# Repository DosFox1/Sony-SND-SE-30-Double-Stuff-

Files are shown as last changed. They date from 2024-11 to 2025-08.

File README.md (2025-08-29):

# Sony-SND-SE-30-Double-Stuff
BETA - A replacement for the Sony SND IC (part number 343-0045-A), specifically designed for the SE/30.
This design is a duplication of the previous Sony SND SMD version, but literally copied twice to fit two Sony SNDs onto the board without the DRC yelling at me.




# So What Is It?
This is quite literally the same design as before, with the same improvement of not needing the -12V rail. 
However, due to the board constraints of the SE/30, two of my SMD boards will not fit - at least easily. 
So this design just adds a second SND replacement so the DRC doesn't yell at me. 

It's all common jellybean parts, so nothing hyper specific is needed.

**Please note that -12V will need to be tapped from somewhere on the board, otherwise the audio doesn't work.**

**Also the 27R Pullup resistor at R11 on the logic board needs to be removed, otherwise POR doesn't work!**

The original SMD Design is here:
https://github.com/DosFox1/Sony-SND-SMT-Replacement

And the very original THT design is here:
https://github.com/DosFox1/Sony-SND-THT-Replacement

**Please Also Note That This Is Completely Untested, Build At Your Own Risk**

# Bill Of Materials:

```blocks
Part     Value          Device                       Package  Library                Sheet

C1       100n 16V       100N_CAP_0603                C0603    Capacitors SMD         1
C2       100n 16V       100N_CAP_0603                C0603    Capacitors SMD         1
C3       100n 16V       100N_CAP_0603                C0603    Capacitors SMD         1
C4       100n 16V       100N_CAP_0603                C0603    Capacitors SMD         1
C5       1u 16V         1U_CAP_0603                  C0603    Capacitors SMD         1
C6       100n 16V       100N_CAP_0603                C0603    Capacitors SMD         1
C7       470p           100P_CAP_0603                C0603    Capacitors SMD         1
C8       1n 50V         10N_CAP_0603                 C0603    Capacitors SMD         1
C9       100n 16V       100N_CAP_0603                C0603    Capacitors SMD         1
C10      100n 16V       100N_CAP_0603                C0603    Capacitors SMD         1
C11      220p           100P_CAP_0603                C0603    Capacitors SMD         1
C12      100n 16V       100N_CAP_0603                C0603    Capacitors SMD         1
C13      100n 16V       100N_CAP_0603                C0603    Capacitors SMD         1
C14      100n 16V       100N_CAP_0603                C0603    Capacitors SMD         1
C15      100n 16V       100N_CAP_0603                C0603    Capacitors SMD         1
C16      100n 16V       100N_CAP_0603                C0603    Capacitors SMD         1
C17      470p           100P_CAP_0603                C0603    Capacitors SMD         1
C18      1n 50V         10N_CAP_0603                 C0603    Capacitors SMD         1
C19      100n 16V       100N_CAP_0603                C0603    Capacitors SMD         1
C20      100n 16V       100N_CAP_0603                C0603    Capacitors SMD         1
C21      220p           100P_CAP_0603                C0603    Capacitors SMD         1
C22      100n 16V       100N_CAP_0603                C0603    Capacitors SMD         1
C23      1u 16V         1U_CAP_0603                  C0603    Capacitors SMD         1
C24      100n 16V       100N_CAP_0603                C0603    Capacitors SMD         1
D1       5.1V           DIODE-ZENER-MMSZ5232BS       SOD-123  SparkFun-DiscreteSemi  1
D2       5.1V           DIODE-ZENER-MMSZ5232BS       SOD-123  SparkFun-DiscreteSemi  1
IC1      TL072          OPAMP-DUALU                  SO08     SparkFun-IC-Amplifiers 1
IC2      4016D          4016D                        SO14     40xx                   1
IC3      NE555DRG4      555_SOIC8                    SOIC8    ICs                    1
IC4      74LVC1G06DBV   74LVC1G06DBV                 SOT23-5  74xx-little-us         1
IC5      Turned Pins    SND Turned Pins              DIP16    Pins                   1
IC6      4016D          4016D                        SO14     40xx                   1
IC7      Turned Pins    SND Turned Pins              DIP16    ICs                    1
IC8      74LVC1G06DBV   74LVC1G06DBV                 SOT23-5  74xx-little-us         1
IC9      NE555DRG4      555_SOIC8                    SOIC8    Pins                   1
IC10     TL072          OPAMP-DUALU                  SO08     SparkFun-IC-Amplifiers 1
Q1       MMBT3906       TRANS_PNP-PMBT3906|MMBT3906L SOT23-3  SparkFun-DiscreteSemi  1
Q2       MMBT3904       TRANS_NPN-MMBT2222AL         SOT23-3  SparkFun-DiscreteSemi  1
Q3       MMBT3906       TRANS_PNP-PMBT3906|MMBT3906L SOT23-3  SparkFun-DiscreteSemi  1
Q4       MMBT3904       TRANS_NPN-MMBT2222AL         SOT23-3  SparkFun-DiscreteSemi  1
R1       1M             GENERIC_RESISTOR_0603        R0603    Resistors SMD          1
R2       1M             GENERIC_RESISTOR_0603        R0603    Resistors SMD          1
R3       6K8            GENERIC_RESISTOR_0603        R0603    Resistors SMD          1
R4       47K            47K_RESISTOR                 R0603    Resistors SMD          1
R5       1k             1K_RESISTOR_0603             R0603    Resistors SMD          1
R6       47K            47K_RESISTOR                 R0603    Resistors SMD          1
R7       68K            GENERIC_RESISTOR_0603        R0603    Resistors SMD          1
R8       150K           GENERIC_RESISTOR_0603        R0603    Resistors SMD          1
R9       470K           GENERIC_RESISTOR_0603        R0603    Resistors SMD          1
R10      470K           GENERIC_RESISTOR_0603        R0603    Resistors SMD          1
R11      200K           GENERIC_RESISTOR_0603        R0603    Resistors SMD          1
R12      150R           150R_RESISTOR_0603           R0603    Resistors SMD          1
R13      47K            47K_RESISTOR                 R0603    Resistors SMD          1
R14      47K            47K_RESISTOR                 R0603    Resistors SMD          1
R15      1M             GENERIC_RESISTOR_0603        R0603    Resistors SMD          1
R16      1M             GENERIC_RESISTOR_0603        R0603    Resistors SMD          1
R17      1k             1K_RESISTOR_0603             R0603    Resistors SMD          1
R18      6K8            GENERIC_RESISTOR_0603        R0603    Resistors SMD          1
R19      68K            GENERIC_RESISTOR_0603        R0603    Resistors SMD          1
R20      150K           GENERIC_RESISTOR_0603        R0603    Resistors SMD          1
R21      470K           GENERIC_RESISTOR_0603        R0603    Resistors SMD          1
R22      470K           GENERIC_RESISTOR_0603        R0603    Resistors SMD          1
R23      200K           GENERIC_RESISTOR_0603        R0603    Resistors SMD          1
R24      150R           150R_RESISTOR_0603           R0603    Resistors SMD          1

```

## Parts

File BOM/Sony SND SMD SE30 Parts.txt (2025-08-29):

Partlist

Exported from SND_SMD_Replacement.sch at 31/Oct/24 13:54

EAGLE Version 9.6.2 Copyright (c) 1988-2020 Autodesk, Inc.

Assembly variant: 

Part     Value          Device                       Package  Library                Sheet

C1       100n 16V       100N_CAP_0603                C0603    Capacitors SMD         1
C2       100n 16V       100N_CAP_0603                C0603    Capacitors SMD         1
C3       100n 16V       100N_CAP_0603                C0603    Capacitors SMD         1
C4       100n 16V       100N_CAP_0603                C0603    Capacitors SMD         1
C5       1u 16V         1U_CAP_0603                  C0603    Capacitors SMD         1
C6       100n 16V       100N_CAP_0603                C0603    Capacitors SMD         1
C7       470p           470P_CAP_0603                C0603    Capacitors SMD         1
C8       1n 50V         1N_CAP_0603                  C0603    Capacitors SMD         1
C9       100n 16V       100N_CAP_0603                C0603    Capacitors SMD         1
C10      100n 16V       100N_CAP_0603                C0603    Capacitors SMD         1
C11      220p           220P_CAP_0603                C0603    Capacitors SMD         1
C12      100n 16V       100N_CAP_0603                C0603    Capacitors SMD         1
C13      100n 16V       100N_CAP_0603                C0603    Capacitors SMD         1
C14      100n 16V       100N_CAP_0603                C0603    Capacitors SMD         1
C15      100n 16V       100N_CAP_0603                C0603    Capacitors SMD         1
C16      100n 16V       100N_CAP_0603                C0603    Capacitors SMD         1
C17      470p           470P_CAP_0603                C0603    Capacitors SMD         1
C18      1n 50V         1N_CAP_0603                  C0603    Capacitors SMD         1
C19      100n 16V       100N_CAP_0603                C0603    Capacitors SMD         1
C20      100n 16V       100N_CAP_0603                C0603    Capacitors SMD         1
C21      220p           220P_CAP_0603                C0603    Capacitors SMD         1
C22      100n 16V       100N_CAP_0603                C0603    Capacitors SMD         1
C23      1u 16V         1U_CAP_0603                  C0603    Capacitors SMD         1
C24      100n 16V       100N_CAP_0603                C0603    Capacitors SMD         1
D1       5.1V           DIODE-ZENER-MMSZ5232BS       SOD-123  SparkFun-DiscreteSemi  1
D2       5.1V           DIODE-ZENER-MMSZ5232BS       SOD-123  SparkFun-DiscreteSemi  1
IC1      TL072          OPAMP-DUALU                  SO08     SparkFun-IC-Amplifiers 1
IC2      4016D          4016D                        SO14     40xx                   1
IC3      NE555DRG4      555_SOIC8                    SOIC8    ICs                    1
IC4      74LVC1G06DBV   74LVC1G06DBV                 SOT23-5  74xx-little-us         1
IC5                     SND                          DIP16    ICs                    1
IC6      4016D          4016D                        SO14     40xx                   1
IC7                     SND                          DIP16    ICs                    1
IC8      74LVC1G06DBV   74LVC1G06DBV                 SOT23-5  74xx-little-us         1
IC9      NE555DRG4      555_SOIC8                    SOIC8    ICs                    1
IC10     TL072          OPAMP-DUALU                  SO08     SparkFun-IC-Amplifiers 1
Q1       MMBT3906       TRANS_PNP-PMBT3906|MMBT3906L SOT23-3  SparkFun-DiscreteSemi  1
Q2       MMBT3904       TRANS_NPN-MMBT2222AL         SOT23-3  SparkFun-DiscreteSemi  1
Q3       MMBT3906       TRANS_PNP-PMBT3906|MMBT3906L SOT23-3  SparkFun-DiscreteSemi  1
Q4       MMBT3904       TRANS_NPN-MMBT2222AL         SOT23-3  SparkFun-DiscreteSemi  1
R1       1M             GENERIC_RESISTOR_0603        R0603    Resistors SMD          1
R2       1M             GENERIC_RESISTOR_0603        R0603    Resistors SMD          1
R3       6K8            GENERIC_RESISTOR_0603        R0603    Resistors SMD          1
R4       47K            47K_RESISTOR                 R0603    Resistors SMD          1
R5       1k             1K_RESISTOR_0603             R0603    Resistors SMD          1
R6       47K            47K_RESISTOR                 R0603    Resistors SMD          1
R7       68K            GENERIC_RESISTOR_0603        R0603    Resistors SMD          1
R8       150K           GENERIC_RESISTOR_0603        R0603    Resistors SMD          1
R9       470K           GENERIC_RESISTOR_0603        R0603    Resistors SMD          1
R10      470K           GENERIC_RESISTOR_0603        R0603    Resistors SMD          1
R11      200K           GENERIC_RESISTOR_0603        R0603    Resistors SMD          1
R12      150R           150R_RESISTOR_0603           R0603    Resistors SMD          1
R13      47K            47K_RESISTOR                 R0603    Resistors SMD          1
R14      47K            47K_RESISTOR                 R0603    Resistors SMD          1
R15      1M             GENERIC_RESISTOR_0603        R0603    Resistors SMD          1
R16      1M             GENERIC_RESISTOR_0603        R0603    Resistors SMD          1
R17      1k             1K_RESISTOR_0603             R0603    Resistors SMD          1
R18      6K8            GENERIC_RESISTOR_0603        R0603    Resistors SMD          1
R19      68K            GENERIC_RESISTOR_0603        R0603    Resistors SMD          1
R20      150K           GENERIC_RESISTOR_0603        R0603    Resistors SMD          1
R21      470K           GENERIC_RESISTOR_0603        R0603    Resistors SMD          1
R22      470K           GENERIC_RESISTOR_0603        R0603    Resistors SMD          1
R23      200K           GENERIC_RESISTOR_0603        R0603    Resistors SMD          1
R24      150R           150R_RESISTOR_0603           R0603    Resistors SMD          1

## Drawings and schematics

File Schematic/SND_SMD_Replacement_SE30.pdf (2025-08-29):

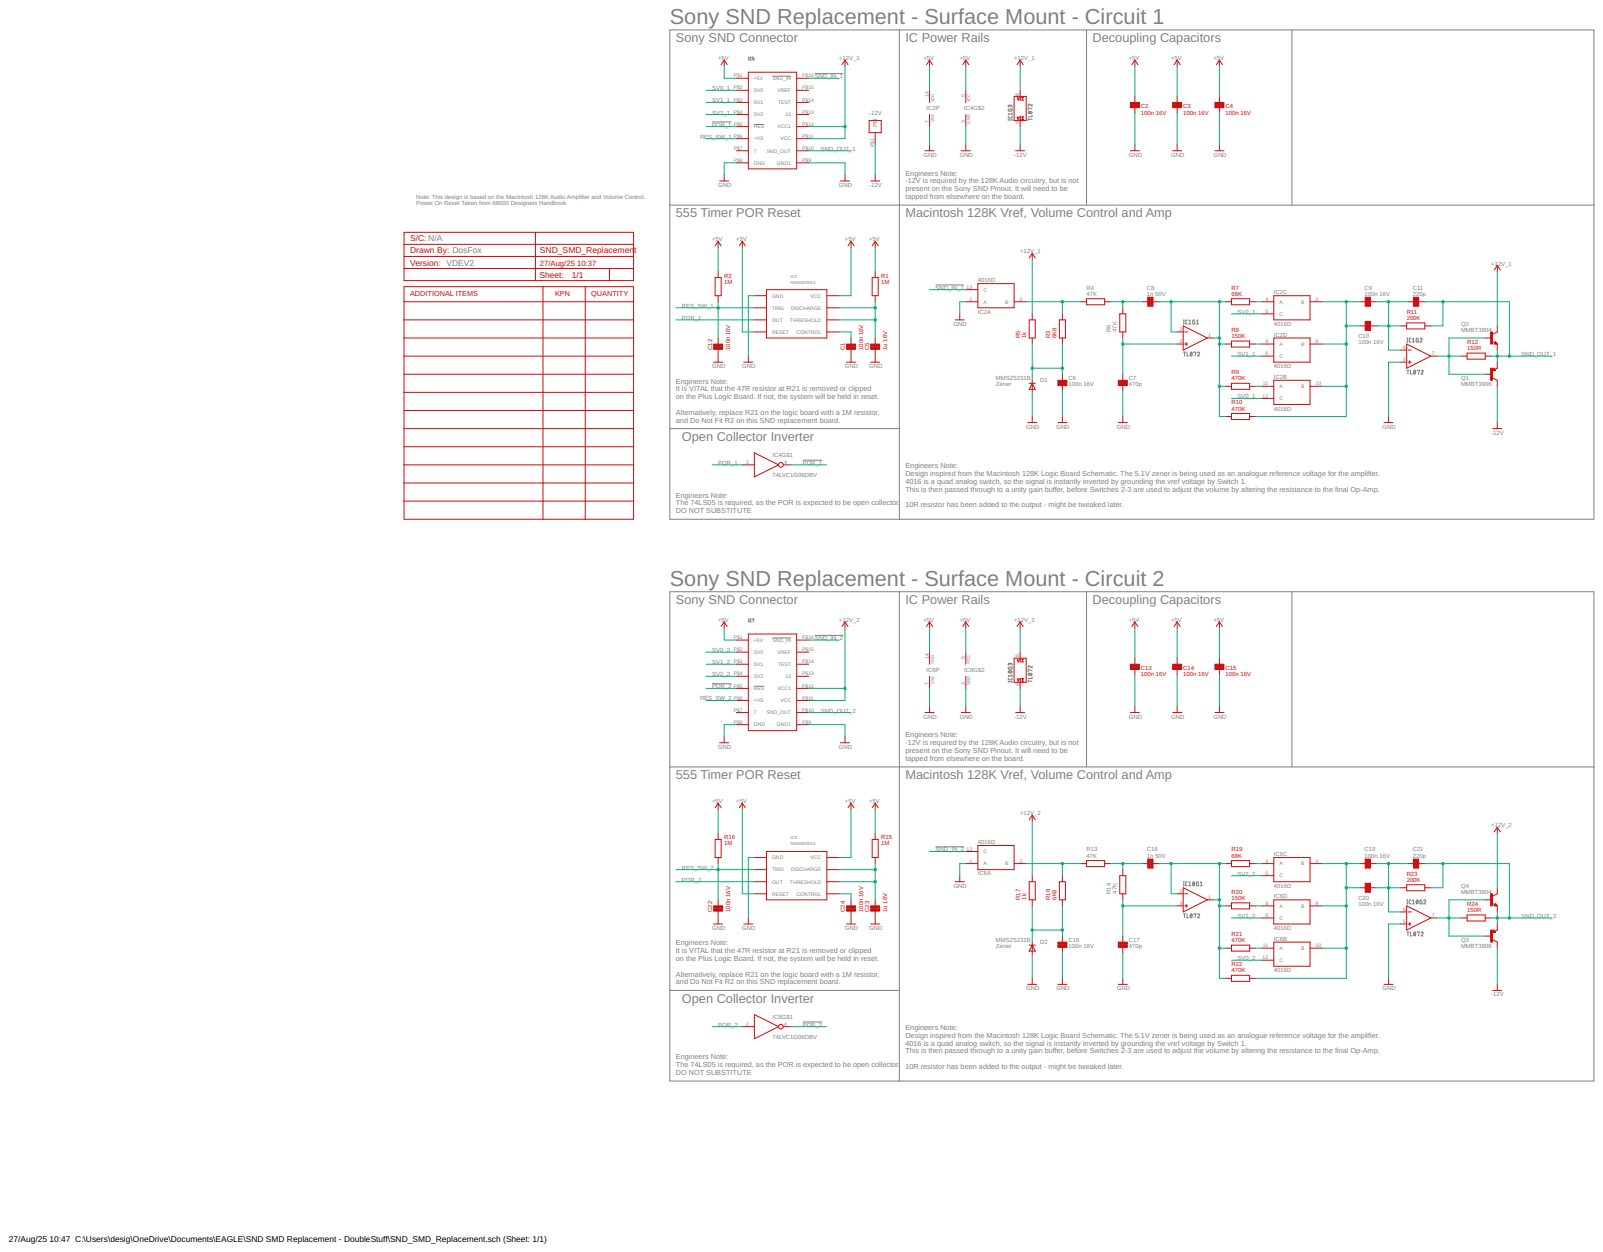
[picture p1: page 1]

Sony SND Replacement - Surface Mount - Circuit 1

Engineers Note: -12V is required by the 128K Audio circuitry, but is not

present on the Sony SND Pinout. It will need to be
tapped from elsewhere on the board.
Macintosh 128K Vref, Volume Control and Amp

Note: This design is based on the Macintosh 128K Audio Amplifier and Volume Control. Power On Reset Taken from 68000 Designers Handbook

S/C: N/A
Drawn By: DosFox | SND_SMD_Replacement
Version: VDEV2 | 27/Aug/25 10:37

Sheet: 1/1

Engineers Note:
It is VITAL that the 47R resistor at R21 is removed or clipped
on the Plus Logic Board. If not, the system will be held in reset. Alternatively, replace R21 on the logic board with a 1M resistor, and Do Not Fit R2 on this SND replacement board.

Design inspired from the Macintosh 128K Logic Board Schematic. The 5.1V zener is being used as an analogue reference voltage for the amplifier. 4016 is a quad analog switch, so the signal is instantly inverted by grounding the vref voltage by Switch 1. This is then passed through to a unity gain buffer, before Switches 2-3 are used to adjust the volume by altering the resistance to the final Op-Amp. 10R resistor has been added to the output - might be tweaked later.

The 74LS05 is required, as the POR is expected to be open collector. DO NOT SUBSTITUTE

Sony SND Replacement - Surface Mount - Circuit 2

27/Aug/25 10:47 C:\Users\desig\OneDrive\Documents\EAGLE\SND SMD Replacement - DoubleStuff\SND_SMD_Replacement.sch (Sheet: 1/1)

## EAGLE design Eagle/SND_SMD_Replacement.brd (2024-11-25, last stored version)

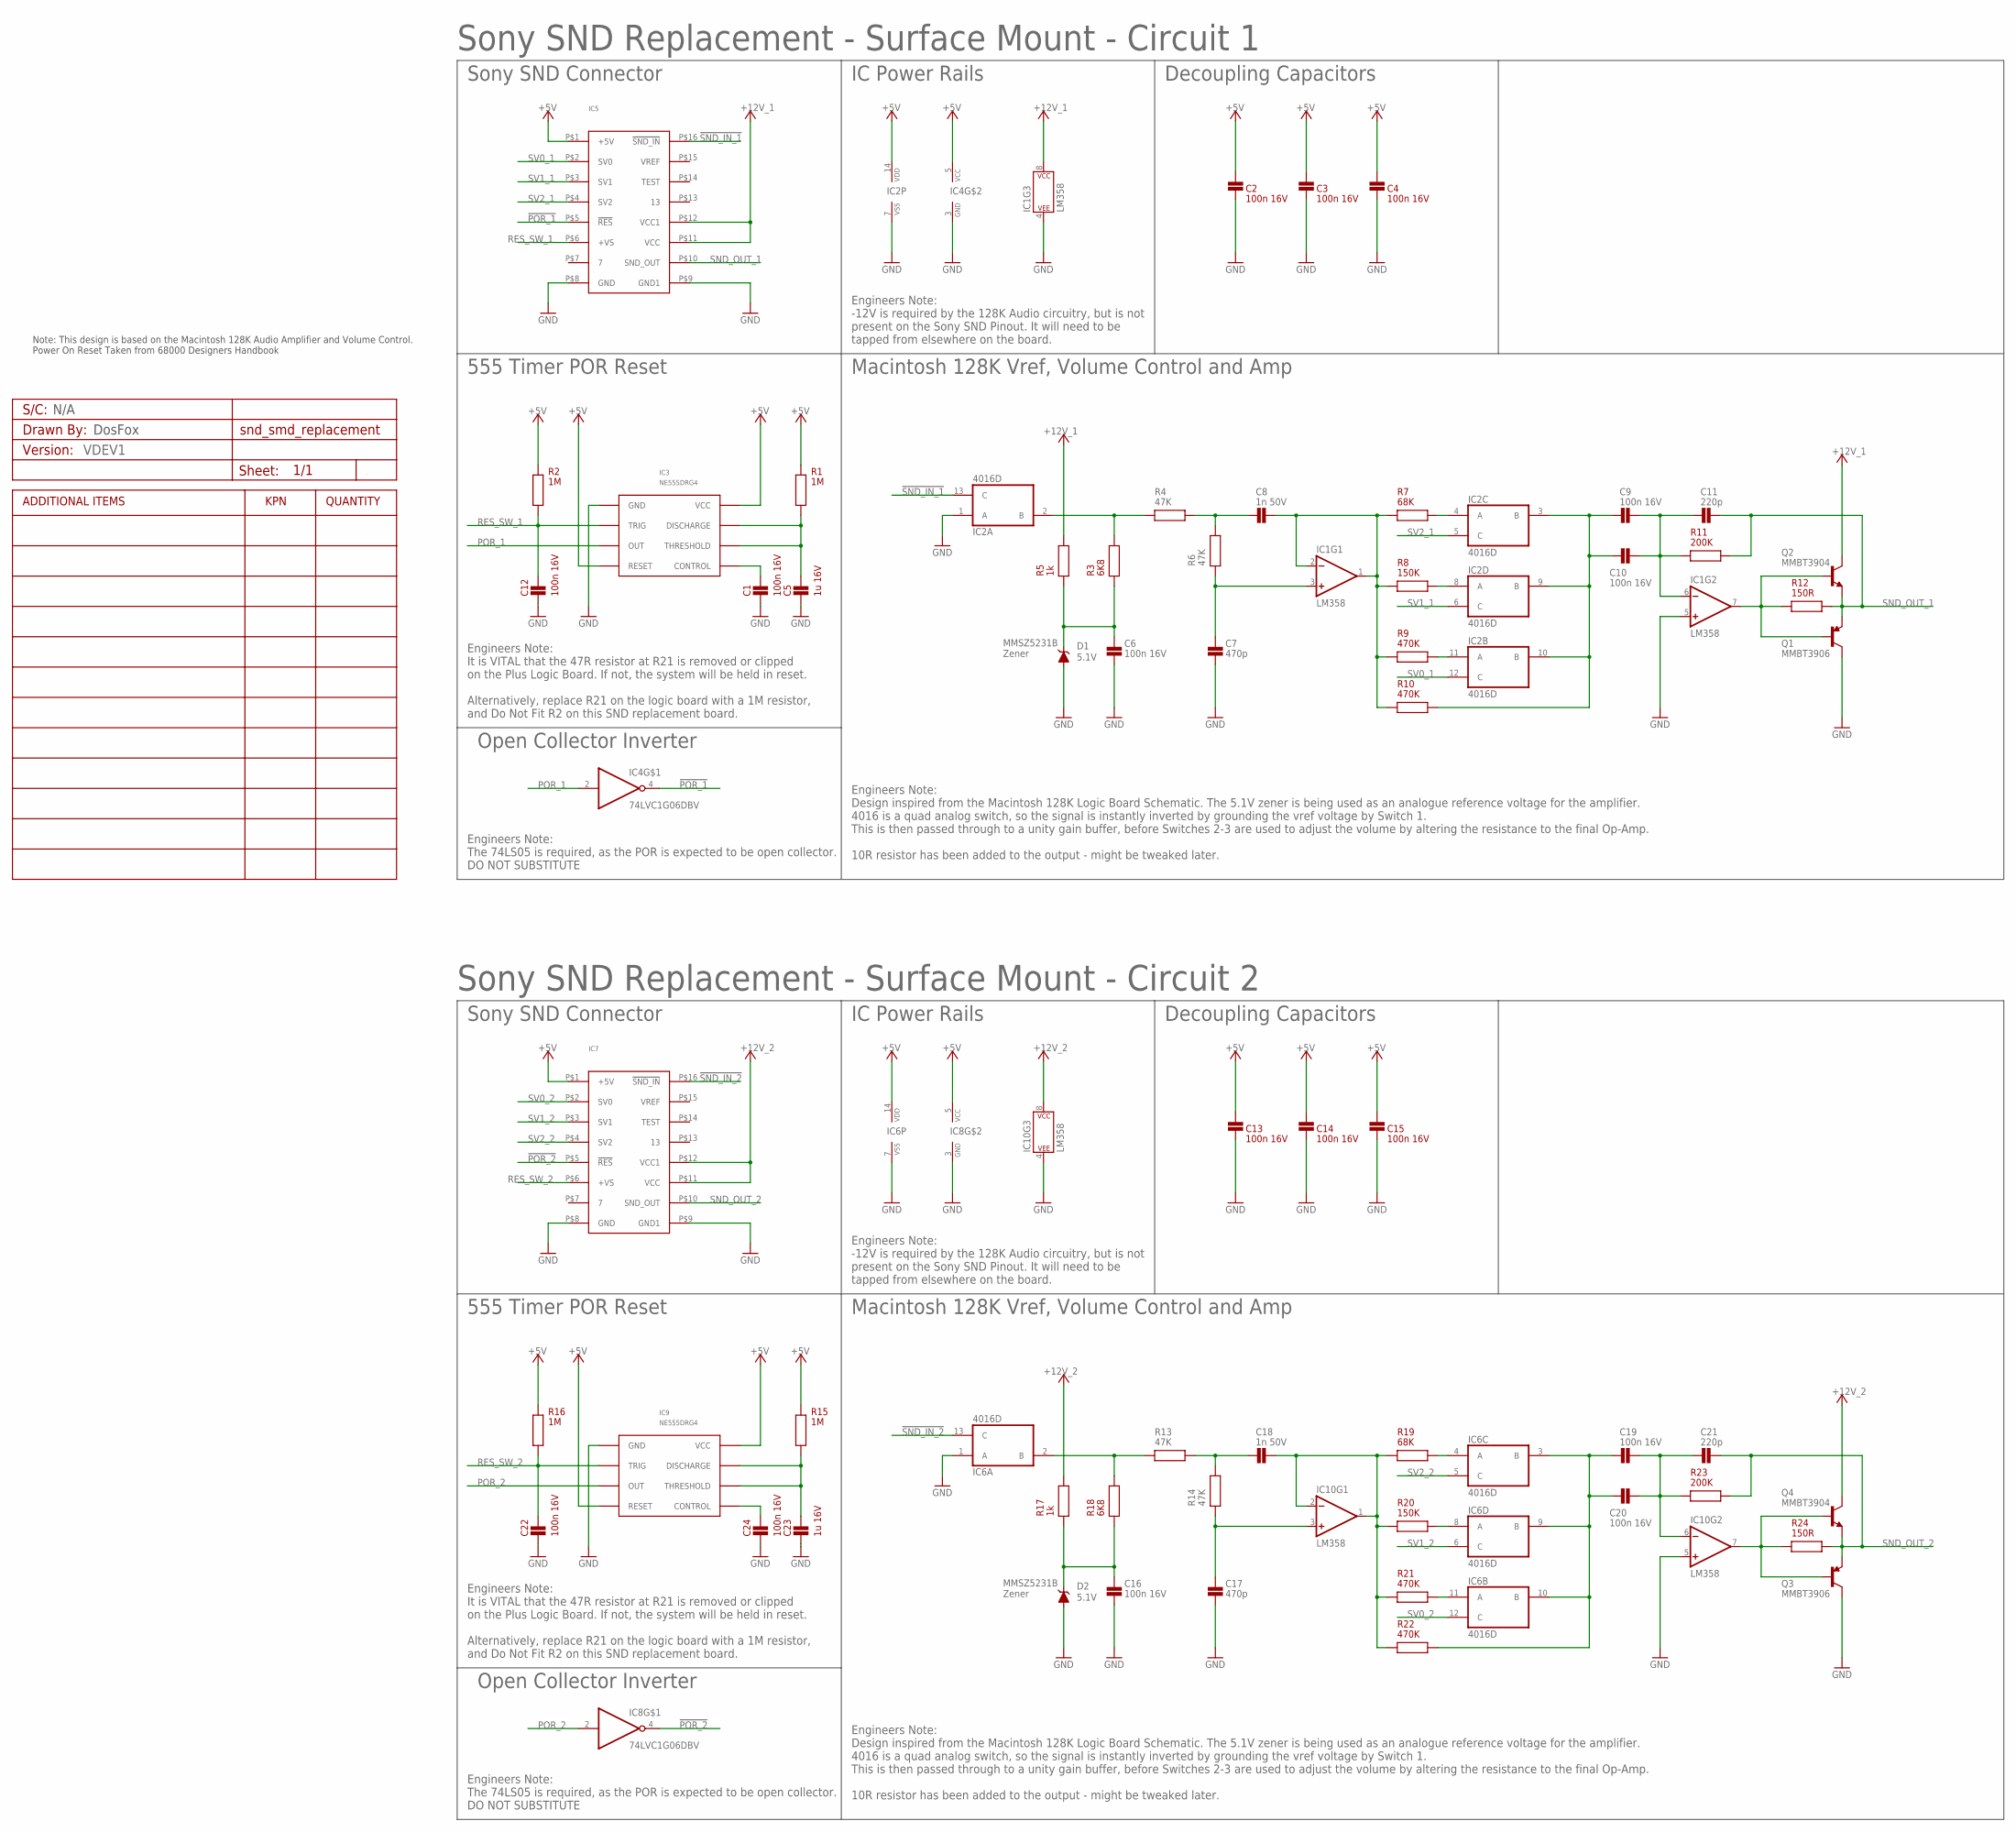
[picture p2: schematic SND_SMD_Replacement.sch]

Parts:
A1: VDEV1; PCB_CUSTOM_DETAILS
C1, C2, C3, C4, C6, C9, C10, C12, C13, C14, C15, C16, C19, C20, C22, C24: 100n 16V; C0603
C5, C23: 1u 16V; C0603
C7, C17: 470p; C0603
C8, C18: 1n 50V; C0603
C11, C21: 220p; C0603
D1, D2: 5.1V; SOD-323
IC1, IC10: LM358; SO08
IC2, IC6: 4016D; SO14
IC3, IC9: NE555DRG4; SOIC8
IC4, IC8: 74LVC1G06DBV; SOT23-5
IC5, IC7: SND; DIP16
Q1, Q3: MMBT3906; SOT23-3
Q2, Q4: MMBT3904; SOT23-3
R1, R2, R15, R16: 1M; R0603
R3, R18: 6K8; R0603
R4, R6, R13, R14: 47K; R0603
R5, R17: 1k; R0603
R7, R19: 68K; R0603
R8, R20: 150K; R0603
R9, R10, R21, R22: 470K; R0603
R11, R23: 200K; R0603
R12, R24: 150R; R0603

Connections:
!POR_1: IC4.4 (O), IC5.P$5 (!RES)
!POR_2: IC7.P$5 (!RES), IC8.4 (O)
!SND_IN_1: IC2.13 (C), IC5.P$16 (!SND_IN)
!SND_IN_2: IC6.13 (C), IC7.P$16 (!SND_IN)
+5V: C2.2, C3.2, C4.2, C13.2, C14.2, C15.2, IC2.14 (VDD), IC3.P$4 (RESET), IC3.P$8 (VCC), IC4.5 (VCC), IC5.P$1 (+5V), IC6.14 (VDD), IC7.P$1 (+5V), IC8.5 (VCC), IC9.P$4 (RESET), IC9.P$8 (VCC), R1.2, R2.2, R15.2, R16.2
+12V_1: IC1.8 (P$V+), IC5.P$11 (VCC), IC5.P$12 (VCC1), Q2.3 (C), R5.2
+12V_2: IC7.P$11 (VCC), IC7.P$12 (VCC1), IC10.8 (P$V+), Q4.3 (C), R17.2
GND: C1.1, C2.1, C3.1, C4.1, C5.1, C6.1, C7.1, C12.1, C13.1, C14.1, C15.1, C16.1, C17.1, C22.1, C23.1, C24.1, D1.A, D2.A, IC1.4 (P$V-), IC1.5 (+IN), IC2.1 (A), IC2.7 (VSS), IC3.P$1 (GND), IC4.3 (GND), IC5.P$8 (GND), IC5.P$9 (GND1), IC6.1 (A), IC6.7 (VSS), IC7.P$8 (GND), IC7.P$9 (GND1), IC8.3 (GND), IC9.P$1 (GND), IC10.4 (P$V-), IC10.5 (+IN), Q1.3 (C), Q3.3 (C)
unnamed: IC2.2 (B), R3.2, R4.1
unnamed: C19.1, C20.1, IC6.3 (B), IC6.9 (B), IC6.10 (B), R22.2
unnamed: C9.1, C10.1, IC2.3 (B), IC2.9 (B), IC2.10 (B), R10.2
unnamed: C8.1, R4.2, R6.2
unnamed: C6.2, D1.C, R3.1, R5.1
unnamed: C7.2, IC1.3 (+IN), R6.1
unnamed: IC2.4 (A), R7.2
unnamed: IC2.8 (A), R8.2
unnamed: IC2.11 (A), R9.2
unnamed: C9.2, C10.2, C11.1, IC1.6 (-IN), R11.1
unnamed: C5.2, IC3.P$6 (THRESHOLD), IC3.P$7 (DISCHARGE), R1.1
unnamed: C8.2, IC1.1 (OUT), IC1.2 (-IN), R7.1, R8.1, R9.1, R10.1
unnamed: IC6.2 (B), R13.1, R18.2
unnamed: C18.1, R13.2, R14.2
unnamed: IC1.7 (OUT), Q1.1 (B), Q2.1 (B), R12.1
unnamed: C16.2, D2.C, R17.1, R18.1
unnamed: C1.2, IC3.P$5 (CONTROL)
unnamed: C17.2, IC10.3 (+IN), R14.1
unnamed: IC6.4 (A), R19.2
unnamed: IC6.8 (A), R20.2
unnamed: IC6.11 (A), R21.2
unnamed: C19.2, C20.2, C21.1, IC10.6 (-IN), R23.1
unnamed: IC10.7 (OUT), Q3.1 (B), Q4.1 (B), R24.1
unnamed: C18.2, IC10.1 (OUT), IC10.2 (-IN), R19.1, R20.1, R21.1, R22.1
unnamed: C23.2, IC9.P$6 (THRESHOLD), IC9.P$7 (DISCHARGE), R15.1
unnamed: C24.2, IC9.P$5 (CONTROL)
POR_1: IC3.P$3 (OUT), IC4.2 (I)
POR_2: IC8.2 (I), IC9.P$3 (OUT)
RES_SW_1: C12.2, IC3.P$2 (TRIG), IC5.P$6 (+VS), R2.1
RES_SW_2: C22.2, IC7.P$6 (+VS), IC9.P$2 (TRIG), R16.1
SND_OUT_1: C11.2, IC5.P$10 (SND_OUT), Q1.2 (E), Q2.2 (E), R11.2, R12.2
SND_OUT_2: C21.2, IC7.P$10 (SND_OUT), Q3.2 (E), Q4.2 (E), R23.2, R24.2
SV0_1: IC2.12 (C), IC5.P$2 (SV0)
SV0_2: IC6.12 (C), IC7.P$2 (SV0)
SV1_1: IC2.6 (C), IC5.P$3 (SV1)
SV1_2: IC6.6 (C), IC7.P$3 (SV1)
SV2_1: IC2.5 (C), IC5.P$4 (SV2)
SV2_2: IC6.5 (C), IC7.P$4 (SV2)

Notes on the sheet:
Note: This design is based on the Macintosh 128K Audio Amplifier and Volume Control. Power On Reset Taken from 68000 Designers Handbook
DosFox
N/A
MMSZ5231B Zener
Sony SND Replacement - Surface Mount - Circuit 1
Sony SND Connector
IC Power Rails
Decoupling Capacitors
555 Timer POR Reset
Open Collector Inverter
Macintosh 128K Vref, Volume Control and Amp
Engineers Note: Design inspired from the Macintosh 128K Logic Board Schematic. The 5.1V zener is being used as an analogue reference voltage for the amplifier. 4016 is a quad analog switch, so the signal is instantly inverted by grounding the vref voltage by Switch 1. This is then passed through to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
Engineers Note: It is VITAL that the 47R resistor at R21 is removed or clipped on the Plus Logic Board. If not, the system will be held in reset. Alternatively, replace R21 on the logic board with a 1M resistor, and Do Not Fit R2 on this SND replacement board.
Engineers Note: The 74LS05 is required, as the POR is expected to be open collector. DO NOT SUBSTITUTE
Engineers Note: -12V is required by the 128K Audio circuitry, but is not present on the Sony SND Pinout. It will need to be tapped from elsewhere on the board.
Sony SND Replacement - Surface Mount - Circuit 2

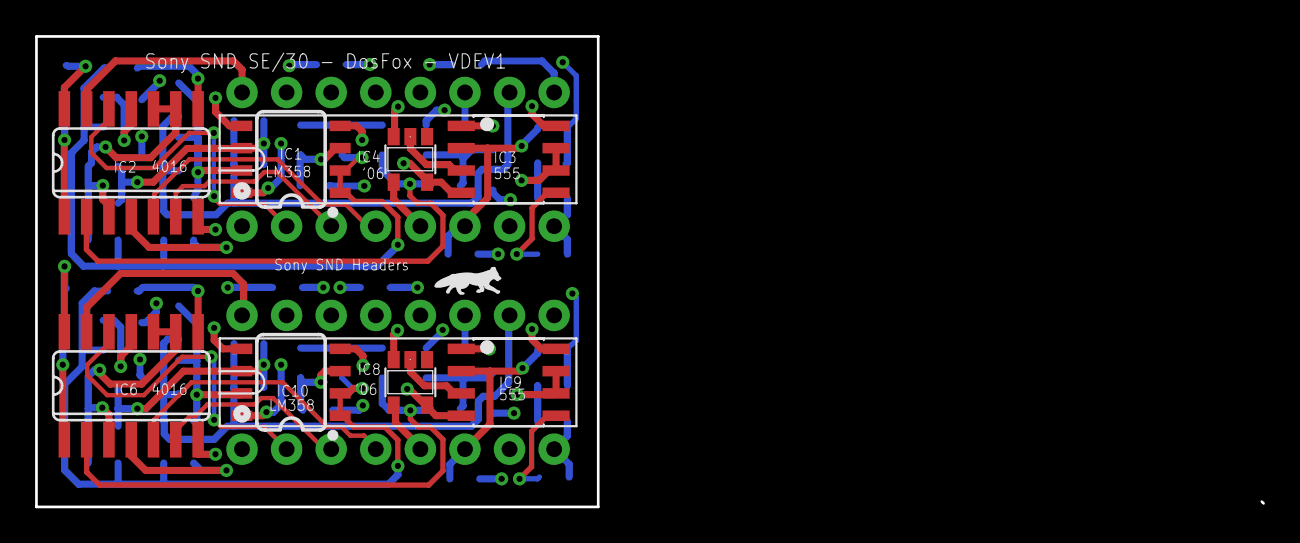
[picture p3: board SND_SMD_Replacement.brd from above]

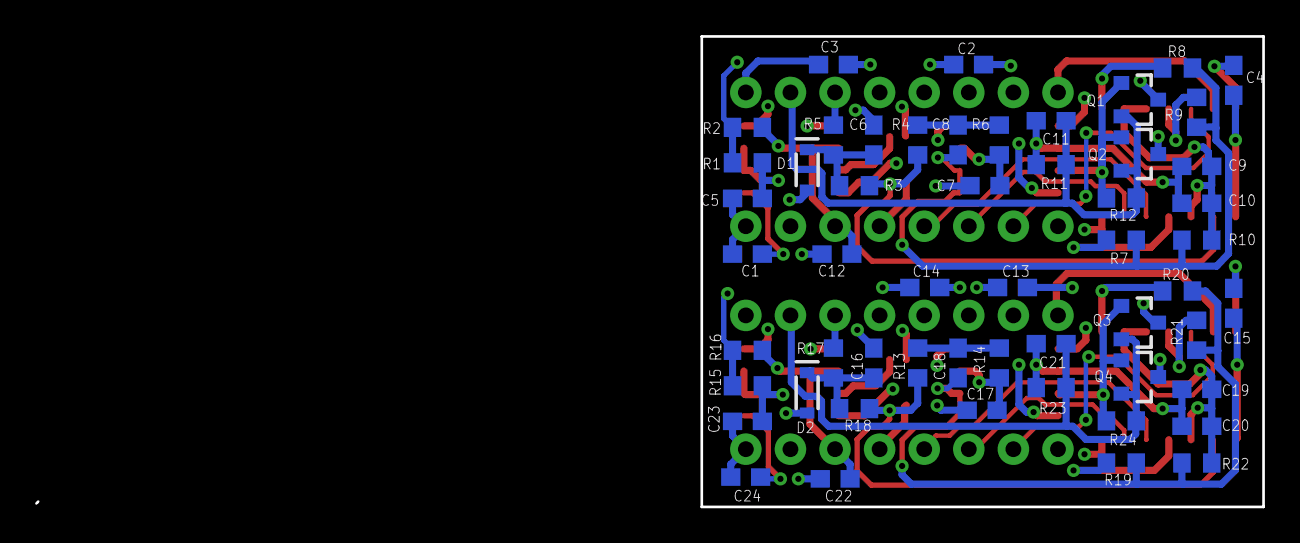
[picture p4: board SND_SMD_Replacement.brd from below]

Board: 4 copper layers, 32.0 x 26.8 mm, 65 parts (54 on the bottom side), 46 nets.

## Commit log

2024-11-25 Add files via upload
    Initial commit of the files for the Double Stuff Sony SND board
    [SND_SMD_Replacement.brd, SND_SMD_Replacement.sch]
2024-11-29 Add files via upload
    Oops. Gerber export was set to two layers - not four.
2024-12-02 Add files via upload
    Regenerated Gerbers using Kicad instead of Eagle. Eagle appears to have issues with four layer boards.

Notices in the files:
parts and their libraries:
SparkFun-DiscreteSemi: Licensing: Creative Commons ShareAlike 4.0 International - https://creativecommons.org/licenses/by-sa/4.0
